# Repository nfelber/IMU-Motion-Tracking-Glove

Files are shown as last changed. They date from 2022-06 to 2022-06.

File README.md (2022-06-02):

# IMU Motion Tracking Glove

We propose a simple open source motion tracking glove prototype based on inertial measurement units (IMUs).
This project was meant to be achieved within a limited amount of time and there are therefore no plans to improve it further.
There are however a lot of potential improvement that can be made starting from our prototype, and anybody is welcome to use it for inspiration or as a base to build upon.

**Authors**: Sara Anejjar, Nathan Felber, Jad Tala, Nicolas S.

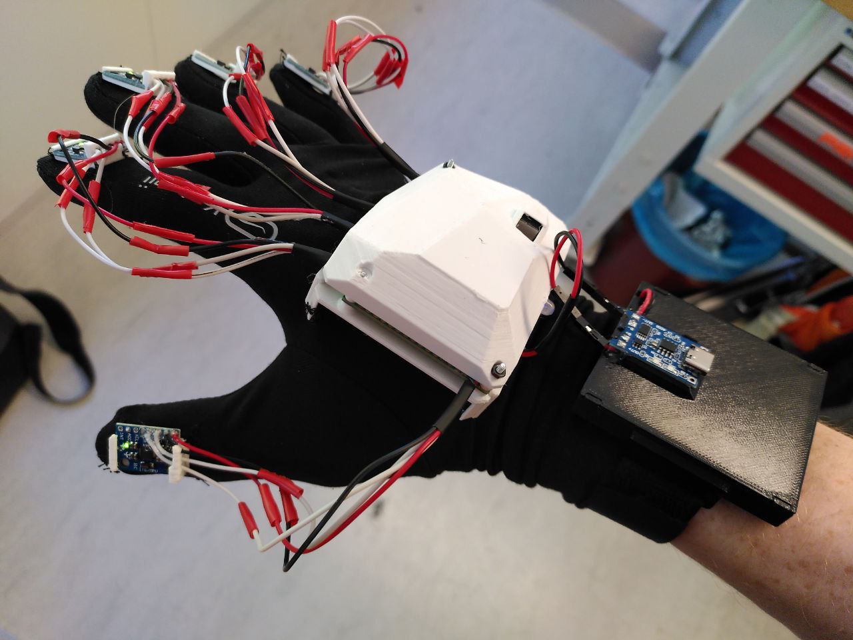
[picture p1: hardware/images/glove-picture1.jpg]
Our glove prototype


# Scope of the project

Many different technologies exist to perform hand and finger tracking, each with their advantages and drawbacks that we will not attempt to detail here.
We decided to explore the usage of IMUs for our prototype, as it is a technology which didn't seem to have been extensively used in motion tracking glove.
Our goal was to build a motion tracking glove from scratch without depending on proprietary VR hardware, and without depending on external computing (such as computer vision done on the user's computer).
Unfortunately, we were not able to do absolute positioning of the hand, which would have enabled our glove to be used in VR applications, but it should still be feasible with some more effort (see #Potential improvements).
Still, we were successfully able to build a prototype which collects and processes data from 6 IMUs, determines the likeliest pose and orientation of the hand from this data and sends the resulting skeleton of the hand to the computer via bluetooth.
We also wrote a driver for the device in Rust together with 3 demo applications.

# Challenges

Inertial measurement units have the advantage of providing a lot of data compared to simpler sensors (such as flex sensors) which allows for detection of a wider range of more subtle gestures.
In theory, that is.
The real challenge is that it is not straightforward to make sense of the data, and arbitrarily complex solutions can be implemented to produce better results.
For our prototype, we limited ourselves to computing the absolute orientation of each IMU, using our single 9-DoF IMU to compensate for the drift of the 5 others.
Our hand pose estimation model then only uses the orientation of the tip of each finger relative to the orientation of the back of the hand.
See #Potential improvements.

# How to replicate

Please refer to the `hardware` folder for how to build the glove itself.
All the software can be found in the `src` folder.

# Potential improvements

- Our prototype is equipped with a camera that could be used to do absolute positioning by detecting the position and distance of two colored markers, and combining this information with the orientation of the camera. Integration of the acceleration of the hand can be fused together with this data using a complementary filter to improve responsiveness and precision. Beware that the amount of image processing that can be done on the hardware we're using is very limited.
- Our pose estimation models only accounts for the orientation of the tip of each fingers. It could be improved by also using the measured dynamic acceleration to discriminate between two finger poses with similar fingertip orientations.

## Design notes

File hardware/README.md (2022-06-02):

# Building instructions

Here are the steps to follow in order to replicate our motion tracking glove prototype.

# Components

Here are listed the components we used.

- 1x ESP32-CAM
- 1x ESP8266 NodeMCU
- 5x MPU-6050 Breakout Board Module
- 1x Adafruit Precision NXP 9-DOF - FXOS8700 + FXAS21002
- 1x Battery Packs Li-Polymer Battery 3.7V 3000mAh
- 1x TC4056A Lithium Battery Charger and Protection Module
- 1x 24x18 holes universal soldering board
- 1x RGB Led (optional)
- 1x glove (running glove for example)

# 3D printed parts

We provide a file `motion-tracking-glove.3mf` ready to be printed with all the parts of the glove.
Please note that it might be better not to print them all at once, as they take a lot of space on the printer's plate.

All the CAD models are found in the `cad` folder.

# Circuit

we built our circuit on a universal soldering board, which made a good compromise between prototyping speed and robustness.

Here are the circuit schematics for the two sides of the soldering board.

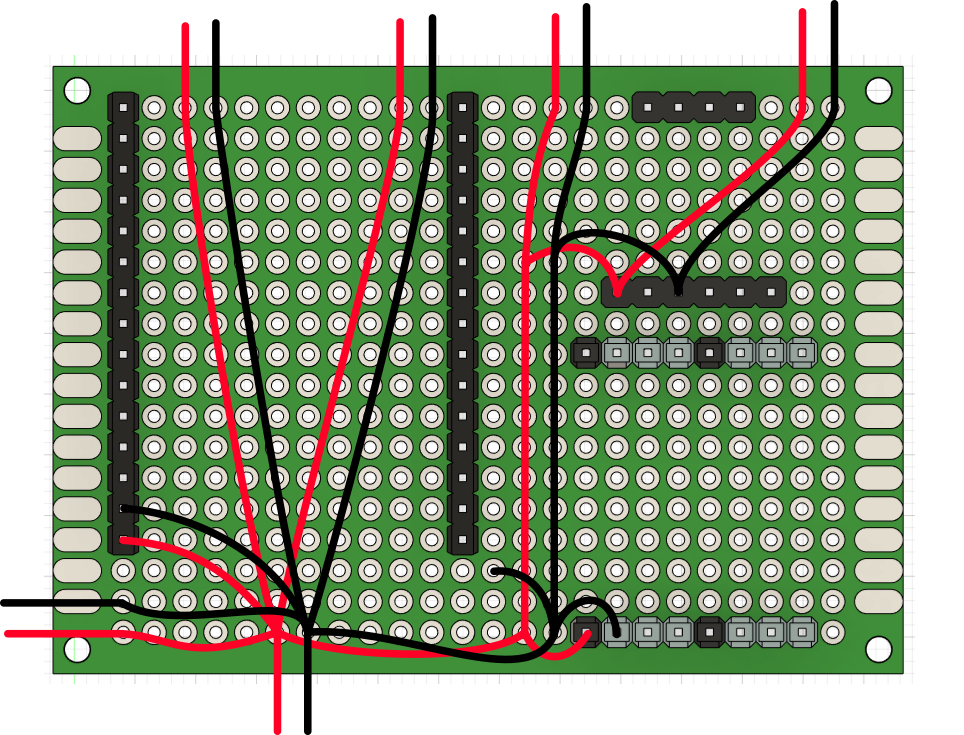
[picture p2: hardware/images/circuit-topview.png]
Top view


On the top side of the board, just under the ESPs and the NXP sensor are found the Vin and Gnd lines for the whole design.
The two wires coming from the bottom of the image are connected to the battery.
All the other wires going out of the image are connected to the corresponding pins of the MPU-6050s.

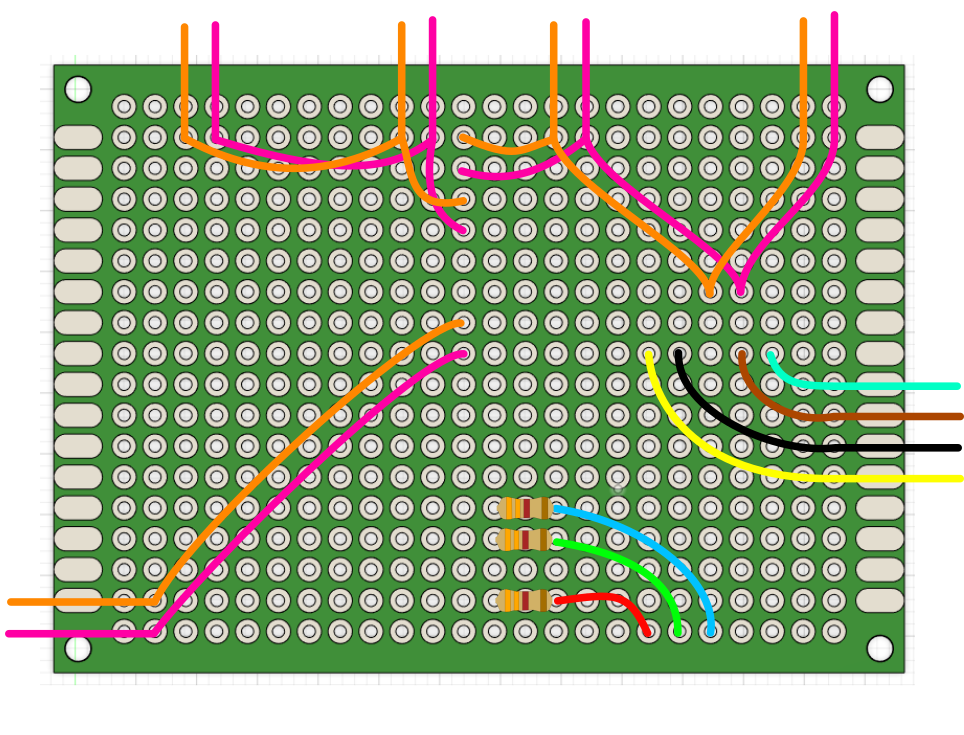
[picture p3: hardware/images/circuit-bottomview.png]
Bottom view


On the bottom side are the I2C lines (SCL: orange, SDA: pink), the RGB led connections (color-coded accordingly) and the 4 wires needed to program the ESP32-cam which doesn't have a USB port.
All the I2C wires going out of the image are connected to the corresponding pins of the MPU-6050s.

# Assembly

## Main part

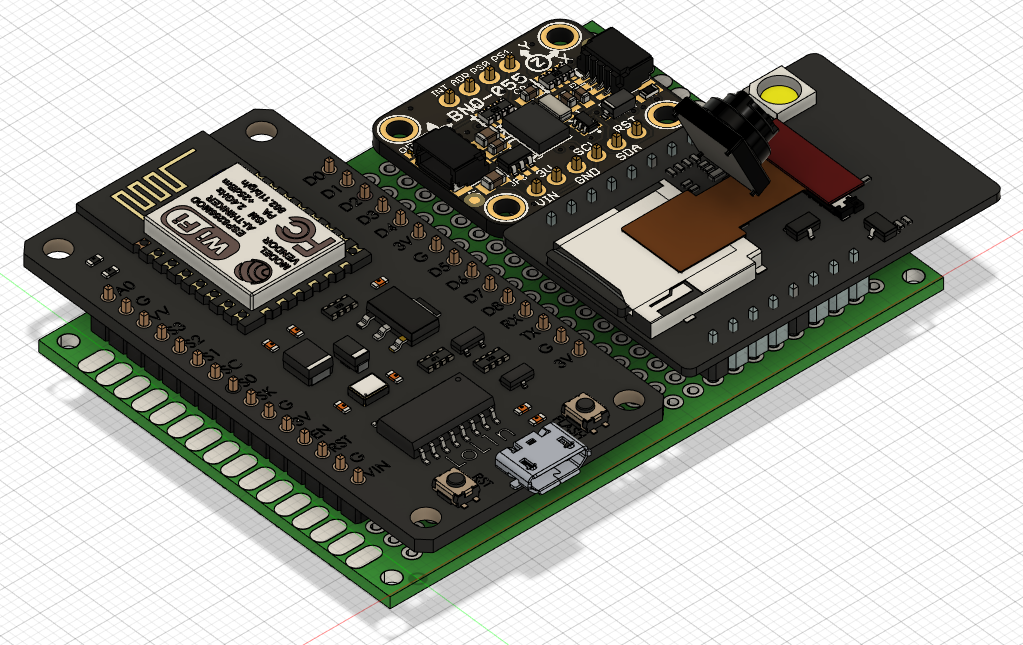
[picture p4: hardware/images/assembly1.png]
Step 1


After the wires have been fullly soldered to the circuit, place the ESP8266, the ESP-CAM, and the NXP sensor as shown in the above image.
Before soldering, verify that the circuit is working as it will be painful to desolder it afterwards.
Then solder the components to the board.
The RGB LED placement is not shown on the image, but each pin of the LED should be soldered at the corresponding place in the circuit.

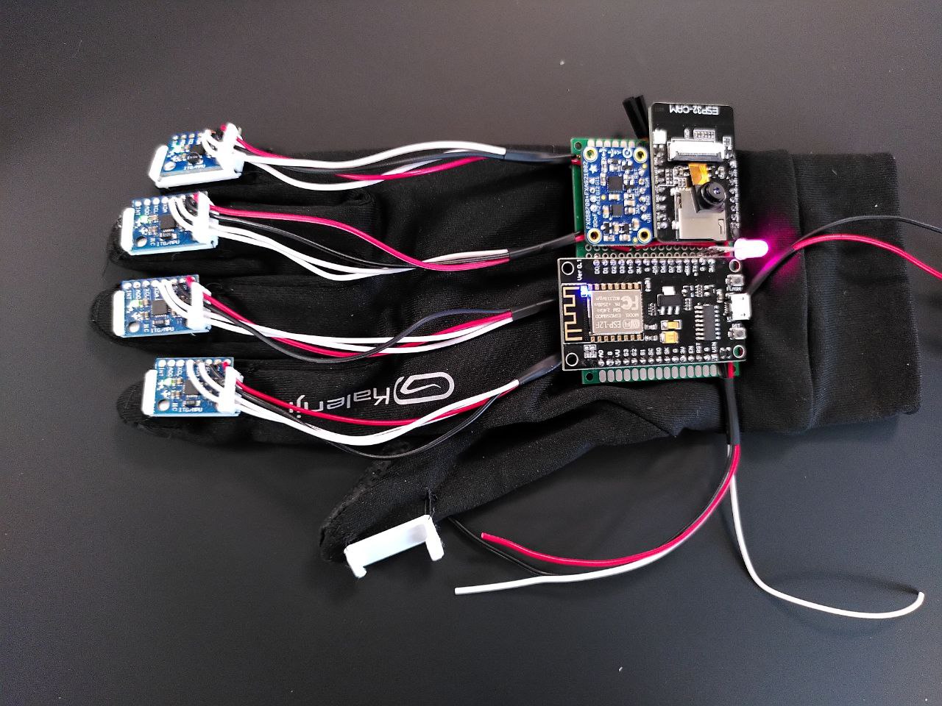
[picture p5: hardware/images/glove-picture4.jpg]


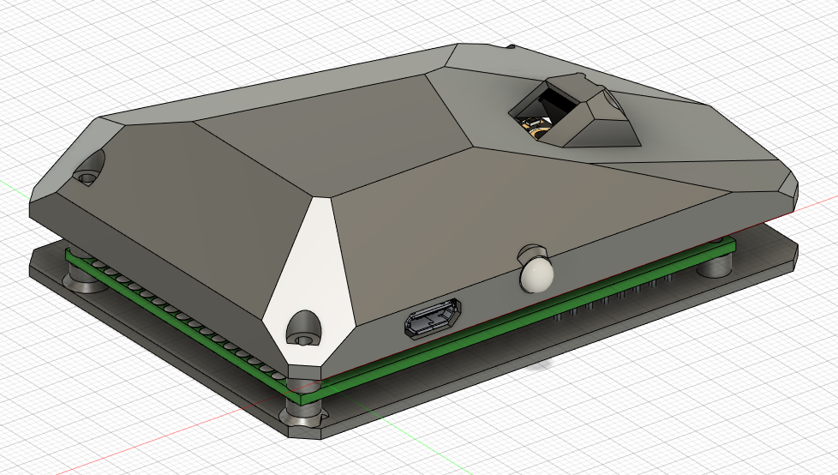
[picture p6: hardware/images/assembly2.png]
Step 2


Once the soldering is finished, assemble the cover and the base plate as shown in the image, and screw them together using M2 screws of the appropriate length.
The camera should be easy enough to fit in its enclosure using the little opening on the top of the cover.

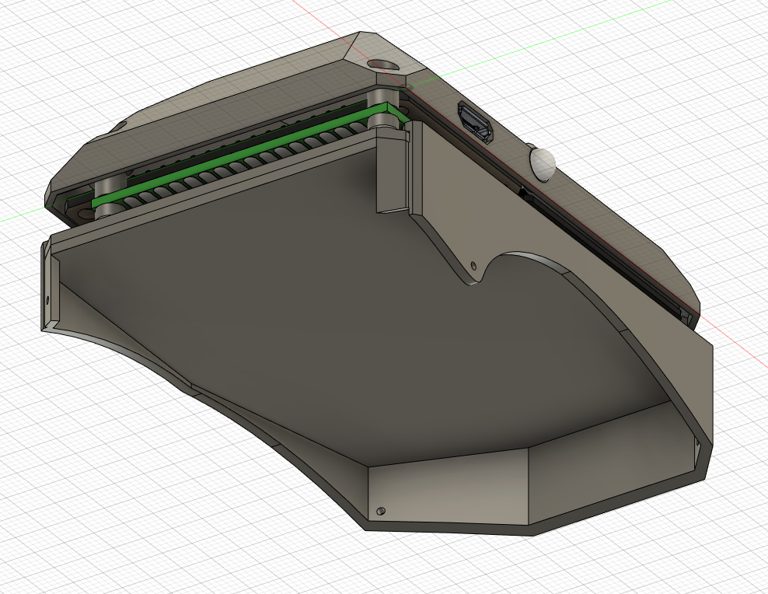
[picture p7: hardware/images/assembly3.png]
Step 3


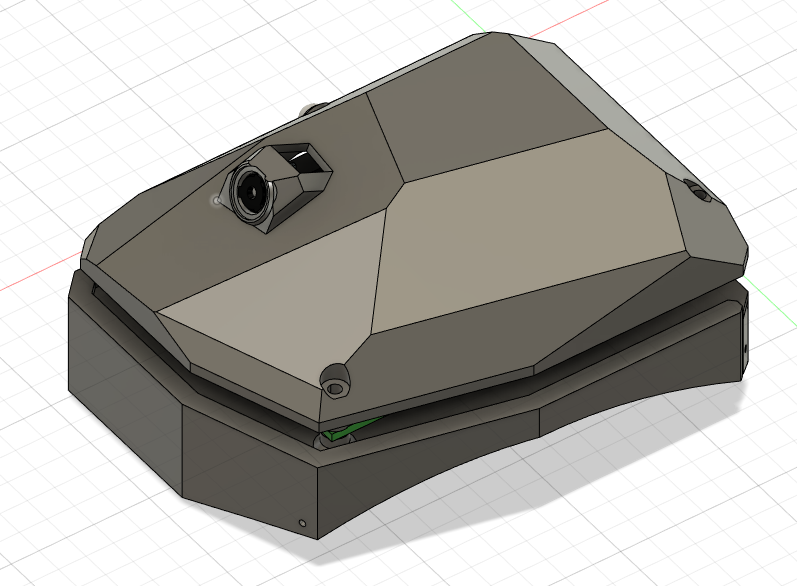
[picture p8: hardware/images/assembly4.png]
Step 4


The whole part can then be slid into main mount's rail.
This mount has 4 holes on its sides so that it can be sewed to the glove.

## MPU mount

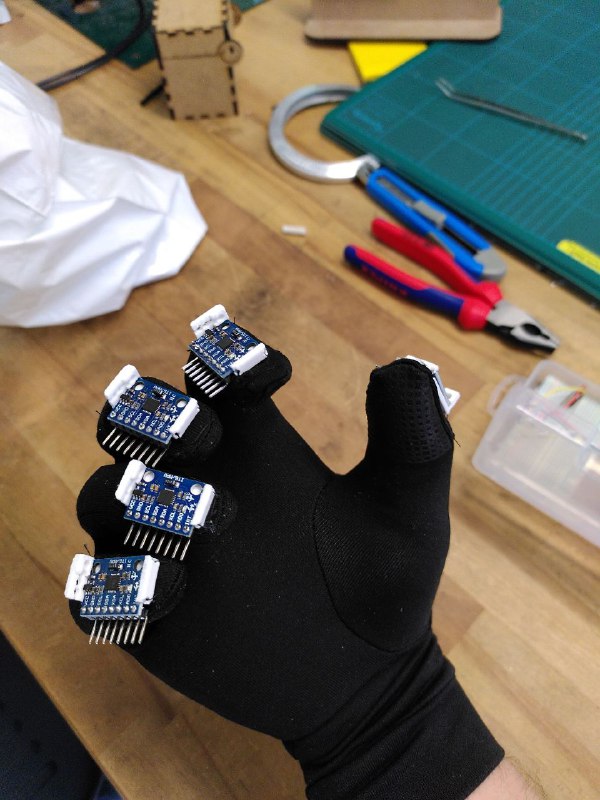
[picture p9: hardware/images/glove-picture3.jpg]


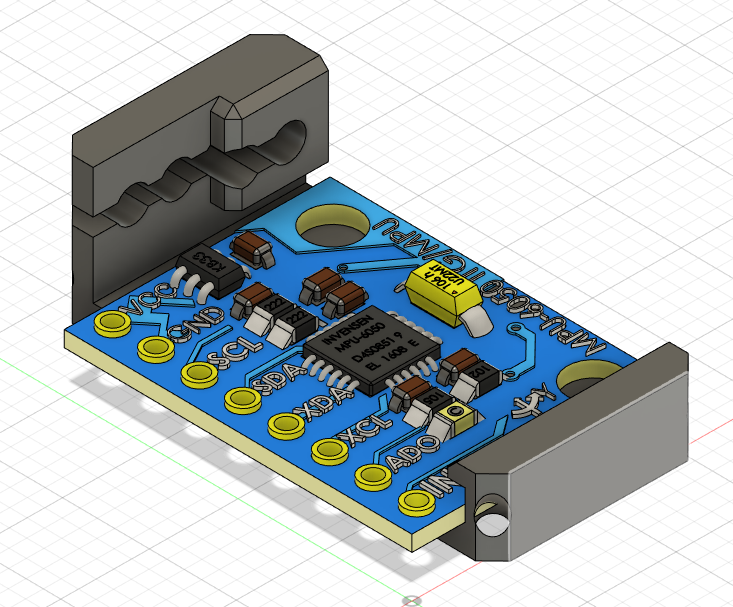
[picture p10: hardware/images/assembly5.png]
Step 5


The MPU-mount is pretty straightforward.
The MPU-6050 is meant to be slid into the rail, and the mount to be sewed to the fingertips of the glove using the four holes on the corners.

## Battery case

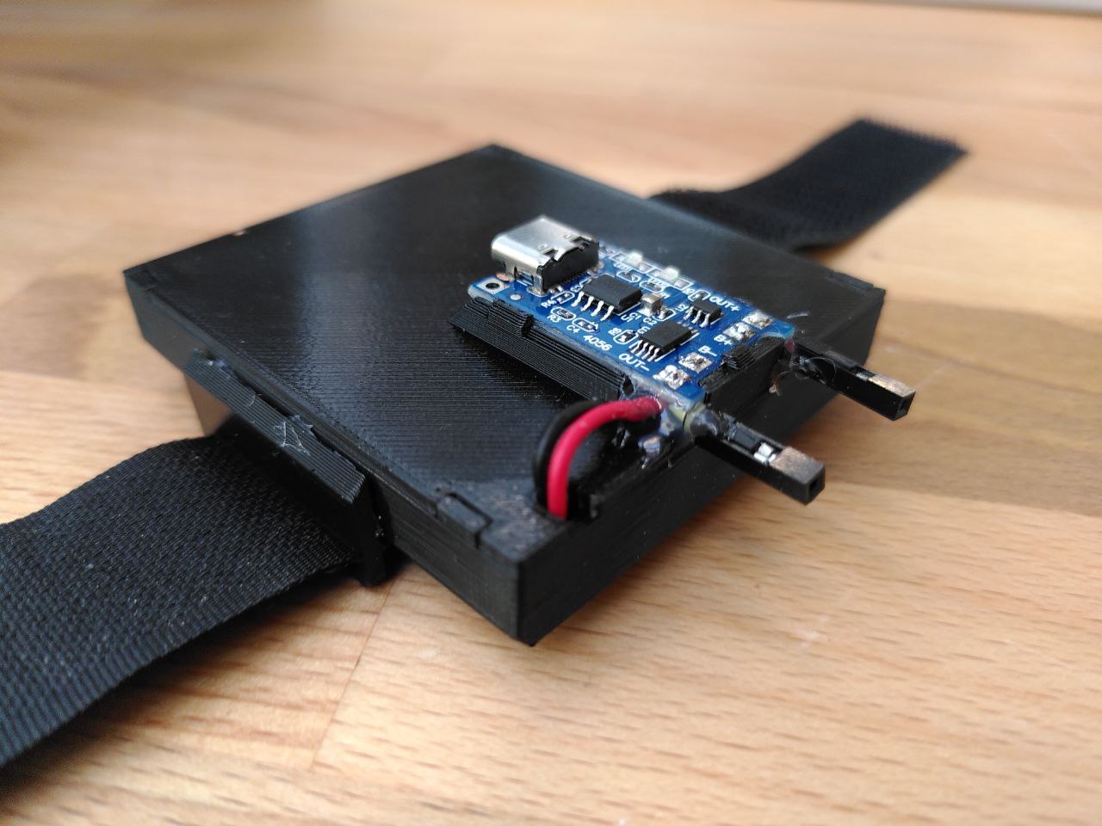
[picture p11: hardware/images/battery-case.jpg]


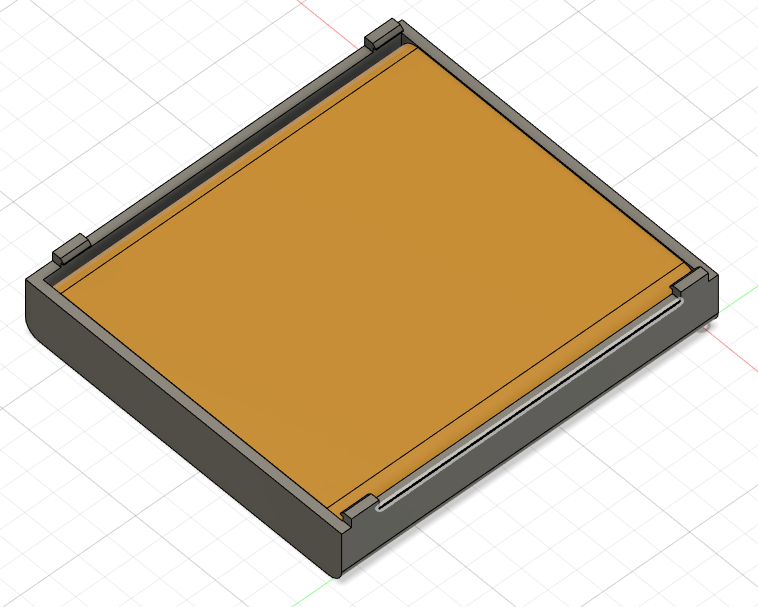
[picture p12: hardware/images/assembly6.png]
Step 6


Place the battery in the case.

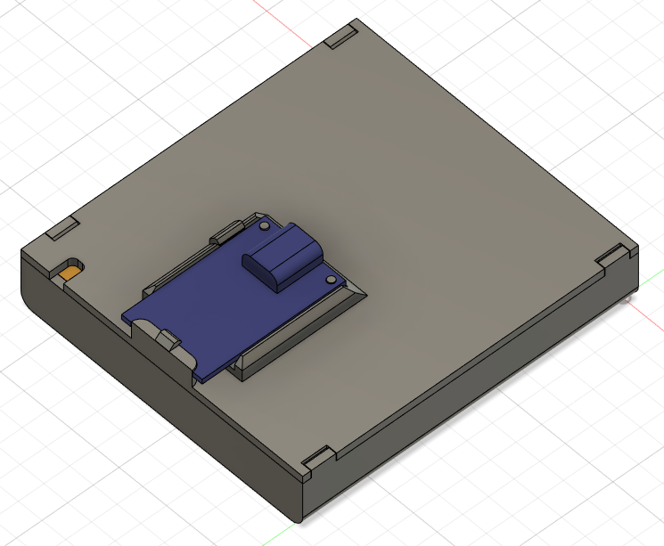
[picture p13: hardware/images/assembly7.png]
Step 7


Close the case with the cover which should snap in the right place.
Then fix the battery charger module as shown in the picture, after having soldered it to the battery wires.

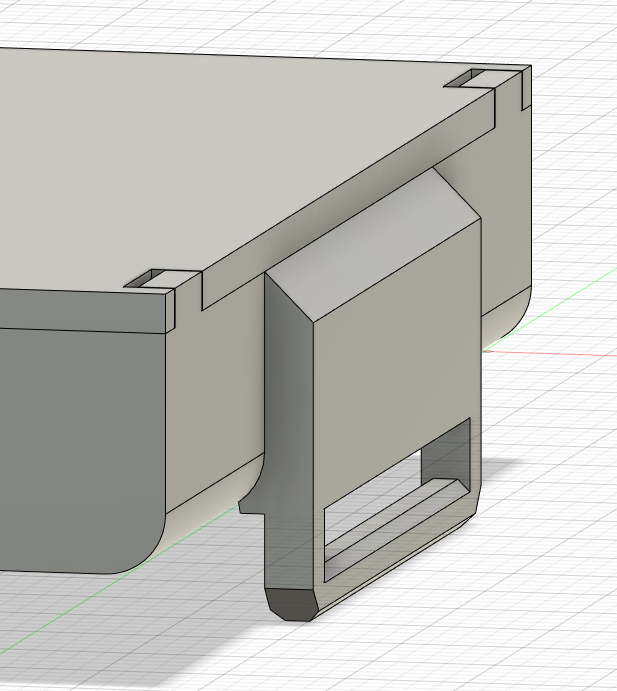
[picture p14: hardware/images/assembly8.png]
Step 8


Finally, fix the wristband loops to the side of the case using hot glue.

## Putting everything together

Here is how it looks when (almost) all the pieces have been put together:

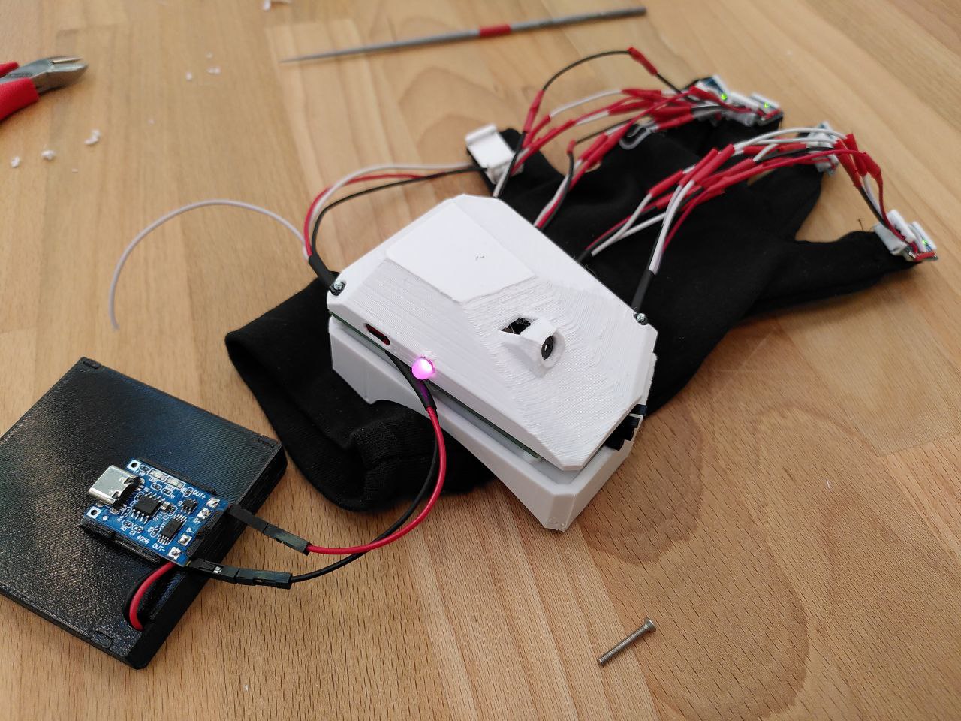
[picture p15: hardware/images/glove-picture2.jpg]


And the final prototype:

MPU mounts

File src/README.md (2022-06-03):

# Software conception

This document explains our software design.

## Dataflow

```
 _______  _______       _______                              _______________
|       ||       |     |       |                            |               |
|       ||       |     |       |                            |    Computer   |
|  MPU  ||  MPU  | ... |  NXP  |                            |               |
|       ||       |     |       |                            |_______________|
|_______||_______|     |_______|                            |...............|
    |        |      :      |                                |:::::::::::::::|
    |--------'------'------'                                |_____|___|_____|
    | I2C raw data                                                  |
 ___|_________                                                      |
|             |                                                     |
|             |                         _____________________       | BLE
|             |                        |                     |      |
|             |                        |                     |      |
|             |     ESP-NOW (wifi)     |                     |      |
|   ESP8266   | ---------------------> |      ESP32-CAM      | -----'
|             |      orientations      |                     |  hand skeleton
|             |                        |   pose-estimation   |
|     AHRS    |                        |_____________________|
|  algorithm  |
|_____________|

```

# ESP8266

The Arduino sketch for the esp8266 can be found inside the `esp8266` folder.
The program uses the [I2cdev](https://github.com/jrowberg/i2cdevlib) library to program the MPU-6050 and communicate with them using the I2C protocol.
It controls the NXP 9-DOF sensor similarily using the [Adafruit AHRS](https://github.com/adafruit/Adafruit_AHRS) library.

The program starts by initialising each sensor.
Then it programs the onboard digital motion processor found on each MPU-6050 so that all the sensor fusion is done on the sensor itself.
Finally, it reads and computes the orientation of each sensor as fast as possible in a 40 ms loop (25 Hz).
The orientation of the NXP sensor is given relative to the absolute (if I'm allowed this misuse of language) reference frame given by the gravity vector and the vector heading north.
The orientation of the MPUs are calculated relative to the orientation of the NXP, and their yaw angle is regularly updated using the NXP as a reference as they tend to drift with time otherwise.

At the end of each loop, these six orientations are then sent to the ESP32-CAM in the form of euler angles using the ESP-NOW wifi protocol.

# ESP32-CAM

The Arduino sketch for the esp8266 can be found inside the `esp32-ble` folder.
This program runs the pose estimation model whose goal is to reconstitute a skeleton of the hand using the orientation data.
The skeleton is composed of 20 joints: 4 for each finger except the thumb which only has 3 and one joint for the wrist.

All the joints have a position in cartesian space relative to the wrist which has position `(0, 0, 0)`.
This way, all the points can easily be translated if some information about the positioning of the hand would be found.

After each update, the program sends the data via bluetooth to the computer on which a running driver can retreive them.

# Rust driver

A simple driver written in [Rust](https://www.rust-lang.org/) can be found in the `MTG-driver` folder.
The crate is very straightforward to use and can provide all the glove's data as well as some very basic gestures detection.

# Demo software

## Debugger

The debugger, found in the `MTG-driver` folder is a simple plotter which displays the hand skeleton as well as all the received data on the screen.
To run it:

```console
$ cargo run --example debugger
```

## Music sequencer

A virtual music sequencer demo is provided in the `midi-sequencer` folder.
For it to work, the virtual loopback MIDI software [LoopMidi](https://www.tobias-erichsen.de/software/loopmidi.html) must be installed and running.
Then, run the program with:

```console
$ cargo run
```

and select the LoopMIDI port.
Then, the virtual MIDI port can be used with any [DAW](https://en.wikipedia.org/wiki/Digital_audio_workstation).

Four virtual knobs control the four notes of the sequencer loop.
Each of them can be grabbed by pinching in front of you with the thumb and a different finger.
There are four additionnal knobs that can be grabbed the same way, but pinching towards the floor.
These additional knobs control the frequency, the cutoff, the base height of every note and the scale that is used.

## Flappy bird

The detailed description of the Flappy Bird game can be found under the following link:
https://github.com/nfelber/IMU-Motion-Tracking-Glove/tree/main/src/flappy_bird

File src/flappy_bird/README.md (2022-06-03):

# FlappyBird
This directory is contains the code and image files allowing to play the Flappy Bird game.

## Launching the Flappy Bird game
To launch the game, follow these steps:

1. Install necessary pygame module by using the command ```pip install pygame```
2. Launch the game using the command ```python3 bird.py```

## Description of our implementation of the Flappy Bird game
Our game is based on the original Flappy Bird game developped by Dong Nguyen in 2013. The gameplay has several particularities that distinguish it from the initial gameplay:
1. There is a chance of 1/3 that instead of a pipe, the player will encounter a wall. The wall cannot be avoided and must thus be "destroyed" by the player making relevant interraction. 
2. In a random manner, the bird enters once every while into a state of madness because of flying without any break. During the state of madness, player loses his control over the bird. The bird will be no longer be willing to react to the player's command to flap his wings. To regain control over the bird, the player has to make relevant interraction.
3. Bird can float in the space at the same level by the player making relevant interraction. While the bird is floating, it will no longer be falling on the ground. However, when the bird enters into the madness state, it is too tired and cannot float anymore.

The goal of the game is to gain the highest score possible. The score is incremented every time that the bird flies between two pipes. The game is over when the bird falls on the ground by either hitting a pipe, a wall or the sky.

## Gameplay
Player can interract with the game's environment in the following manners:
1. By moving the glove fast enough or clicking on the mouse, the flappy bird will flap his wings and jump higher in space.
2. By making gesture 1 or pressing space, any wall that the player encounters gets destroyed.
2. By making gesture 2 or pressing n during the state of madness, the bird becomes normal once again and the player regains control over it.
3. By making gesture 3 or holding h, the bird floats at the same level in space.
4. By making gesture 4 or pressing the button on the screen, player can reset the game.

## Gestures
The gestures that the player can make are the following:
1. Gesture 1: bend all your fingers
2. Gesture 2: bend your index and little finger
3. Gesture 3: bend your middle finger, ring finger and little finger
4. Gesture 4: bend your thumb, ring and little finger

## Source of used images:
The images that our game uses come from the following sources:
- Flappy Bird texture 1: https://openclipart.org/detail/239673/flying-bird-3-frame-1
- Flappy Bird texture 2: https://openclipart.org/detail/239674/flying-bird-3-frame-2
- Flappy Bird texture 3: https://openclipart.org/detail/239675/flying-bird-3-frame-3
- Flappy Bird texture 4: https://openclipart.org/detail/239676/flying-bird-3-frame-4
- Background: http://clipart-library.com/clipart/761360.htm
- Ground: https://www.pikpng.com/pngvi/hmimmh_ground-flappy-bird-ground-scratch-clipart/
- Pipe: https://www.nicepng.com/ourpic/u2q8w7e6e6y3o0q8_flappy-bird-pipes-png-bottle/
- Brick wall obstacle: https://www.pngwing.com/en/free-png-zbvly
- Game over skull texture: https://openclipart.org/detail/248773/skull-and-cross-bones

All images that are not listed here come are images that were created by us by modifying aforementionned images.

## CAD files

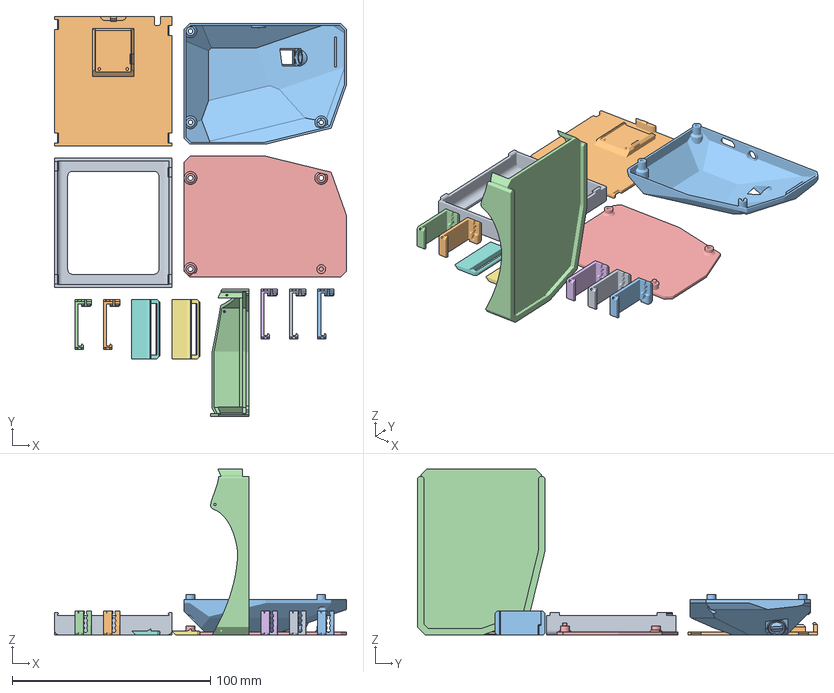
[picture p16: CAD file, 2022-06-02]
hardware/motion-tracking-glove.3mf
147.4 x 201.9 x 83.7 mm
battery-case-bottom.stl
battery-case-top.stl
cover.stl
fixation.stl
main-mount.stl
mpu-mount.stl x 5
wristband.stl x 2

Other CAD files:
hardware/cad/battery-case.f3d
hardware/cad/mpu-mount .f3z

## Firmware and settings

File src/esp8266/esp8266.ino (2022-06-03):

#include "I2Cdev.h"
#include "MPU6050_6Axis_MotionApps612.h"
#include "Wire.h"
#include <Adafruit_Sensor_Calibration.h>
#include <Adafruit_AHRS.h>
#include <Adafruit_FXAS21002C.h>
#include <Adafruit_FXOS8700.h>

#include <Arduino.h>
#include <ESP8266WiFi.h>
#include <espnow.h>

Adafruit_Sensor *accelerometer, *gyroscope, *magnetometer;
Adafruit_NXPSensorFusion filter;
#if defined(ADAFRUIT_SENSOR_CALIBRATION_USE_EEPROM)
  Adafruit_Sensor_Calibration_EEPROM cal;
#else
  Adafruit_Sensor_Calibration_SDFat cal;
#endif

#define FILTER_UPDATE_RATE_HZ 25
//#define FILTER_UPDATE_RATE_HZ 34
Adafruit_FXOS8700 fxos = Adafruit_FXOS8700(0x8700A, 0x8700B);
Adafruit_FXAS21002C fxas = Adafruit_FXAS21002C(0x0021002C);


const int offsets[30] = {
  -2250,  733,  360,  37, 21, -167,
  -3392,  347,  176,  -39,  39, -45,
  -1518,  2031, 1416, 62, -6, 52,
  -312, -3249,  1576, -354, 33, 66,
  -348, 523,  848,  67, 128,  9
};

const int I2C_BUS0_SDA = 12;
const int I2C_BUS0_SCL = 14;
const int I2C_BUS12_SDA = 2;
const int I2C_BUS12_SCL = 0;
const int I2C_BUS34_SDA = 4;
const int I2C_BUS34_SCL = 5;

const int I2C_FREQ = 400000;
const int DMP_PACKET_SIZE = 28;

MPU6050 sensor0(0x68);
MPU6050 sensor1(0x68);
MPU6050 sensor2(0x69);
MPU6050 sensor3(0x68);
MPU6050 sensor4(0x69);

bool dmpReady = false;  // set true if DMP init was successful
uint16_t packetSize;    // expected DMP packet size (default is 42 bytes)
uint16_t fifoCount;     // count of all bytes currently in FIFO
uint8_t fifoBuffer[64]; // FIFO storage buffer

uint8_t broadcastAddress[] = {0xB4, 0xE6, 0x2D, 0xF9, 0x90, 0x45};

typedef struct {
  float euler0[3];
  float euler1[3];
  float euler2[3];
  float euler3[3];
  float euler4[3];
  float euler5[3];
} data_t;

data_t angles;
Quaternion nxp_q, zRotation0, zRotation1, zRotation2, zRotation3, zRotation4;

void setup() {
  Serial.begin(115200);
  Serial.println("Setting up wifi...");
  
  WiFi.mode(WIFI_STA);
  
  // Get Mac Add
  Serial.print("Mac Address: ");
  Serial.println(WiFi.macAddress());
  Serial.println("ESP-Now Sender");
  
  // Initializing the ESP-NOW
  if (esp_now_init() != 0) {
    Serial.println("Problem during ESP-NOW init");
    return;
  }
  
  esp_now_set_self_role(ESP_NOW_ROLE_CONTROLLER);
  
  esp_now_add_peer(broadcastAddress, ESP_NOW_ROLE_SLAVE, 1, NULL, 0);
  Serial.println("Added peer ESP32.");
  
  esp_now_register_send_cb(onSent);
  
  Serial.println("Successfully initialized wifi.");
  
  Serial.println(F("\nInitializing I2C devices..."));
  Serial.println(F("Sensor0:"));
  init_sensor(sensor0, &offsets[0], I2C_BUS0_SDA, I2C_BUS0_SCL);
  Serial.println(F("Sensor1:"));
  init_sensor(sensor1, &offsets[6], I2C_BUS12_SDA, I2C_BUS12_SCL);
  Serial.println(F("Sensor2:"));
  init_sensor(sensor2, &offsets[12], I2C_BUS12_SDA, I2C_BUS12_SCL);
  Serial.println(F("Sensor3:"));
  init_sensor(sensor3, &offsets[18], I2C_BUS34_SDA, I2C_BUS34_SCL);
  Serial.println(F("Sensor4:"));
  init_sensor(sensor4, &offsets[24], I2C_BUS34_SDA, I2C_BUS34_SCL);
  Serial.println(F("Sensor5:"));
  init_NXP(I2C_BUS34_SDA, I2C_BUS34_SCL);

  Serial.println(F("\nInitializing I2C devices..."));
  Serial.println(F("Sensor0:"));
  program_sensor(sensor0, I2C_BUS0_SDA, I2C_BUS0_SCL);
  Serial.println(F("Sensor1:"));
  program_sensor(sensor1, I2C_BUS12_SDA, I2C_BUS12_SCL);
  Serial.println(F("Sensor2:"));
  program_sensor(sensor2, I2C_BUS12_SDA, I2C_BUS12_SCL);
  Serial.println(F("Sensor3:"));
  program_sensor(sensor3, I2C_BUS34_SDA, I2C_BUS34_SCL);
  Serial.println(F("Sensor4:"));
  program_sensor(sensor4, I2C_BUS34_SDA, I2C_BUS34_SCL);
  
  filter.begin(FILTER_UPDATE_RATE_HZ);
  unsigned long t;
  while (true) {
    t = millis();
    read_sensors();
    print_euler(angles.euler0);
    Serial.print(" | ");
    print_euler(angles.euler1);
    Serial.print(" | ");
    print_euler(angles.euler2);
    Serial.print(" | ");
    print_euler(angles.euler3);
    Serial.print(" | ");
    print_euler(angles.euler4);
    Serial.print(" | ");
    print_euler(angles.euler5);
    
    Serial.print(" - ");
    Serial.println(millis() - t);

    send_data();
  }
}

void loop() {
//  Serial.println(F("\ni=init, p=program, c=calibrate, r=read: "));
//  while (!Serial.available());
//  char c = Serial.read();
//
//  if (c == 'i') {
//    Serial.println(F("\nInitializing I2C devices..."));
//    Serial.println(F("Sensor0:"));
//    init_sensor(sensor0, &offsets[0], I2C_BUS0_SDA, I2C_BUS0_SCL);
//    Serial.println(F("Sensor1:"));
//    init_sensor(sensor1, &offsets[6], I2C_BUS12_SDA, I2C_BUS12_SCL);
//    Serial.println(F("Sensor2:"));
//    init_sensor(sensor2, &offsets[12], I2C_BUS12_SDA, I2C_BUS12_SCL);
//    Serial.println(F("Sensor3:"));
//    init_sensor(sensor3, &offsets[18], I2C_BUS34_SDA, I2C_BUS34_SCL);
//    Serial.println(F("Sensor4:"));
//    init_sensor(sensor4, &offsets[24], I2C_BUS34_SDA, I2C_BUS34_SCL);
//    Serial.println(F("Sensor5:"));
//    init_NXP(I2C_BUS34_SDA, I2C_BUS34_SCL);
//  } else if (c == 'p') {
//    Serial.println(F("\nInitializing I2C devices..."));
//    Serial.println(F("Sensor0:"));
//    program_sensor(sensor0, I2C_BUS0_SDA, I2C_BUS0_SCL);
//    Serial.println(F("Sensor1:"));
//    program_sensor(sensor1, I2C_BUS12_SDA, I2C_BUS12_SCL);
//    Serial.println(F("Sensor2:"));
//    program_sensor(sensor2, I2C_BUS12_SDA, I2C_BUS12_SCL);
//    Serial.println(F("Sensor3:"));
//    program_sensor(sensor3, I2C_BUS34_SDA, I2C_BUS34_SCL);
//    Serial.println(F("Sensor4:"));
//    program_sensor(sensor4, I2C_BUS34_SDA, I2C_BUS34_SCL);
//  } else if (c == 'c') {
//    Serial.println(F("\nInitializing I2C devices..."));
//    Serial.println(F("Sensor0:"));
//    calibrate_sensor(sensor0, I2C_BUS0_SDA, I2C_BUS0_SCL);
//    Serial.println(F("Sensor1:"));
//    calibrate_sensor(sensor1, I2C_BUS12_SDA, I2C_BUS12_SCL);
//    Serial.println(F("Sensor2:"));
//    calibrate_sensor(sensor2, I2C_BUS12_SDA, I2C_BUS12_SCL);
//    Serial.println(F("Sensor3:"));
//    calibrate_sensor(sensor3, I2C_BUS34_SDA, I2C_BUS34_SCL);
//    Serial.println(F("Sensor4:"));
//    calibrate_sensor(sensor4, I2C_BUS34_SDA, I2C_BUS34_SCL);
//  } else if (c == 'r') {
//    filter.begin(FILTER_UPDATE_RATE_HZ);
//    unsigned long t;
//    while (true) {
//      t = millis();
//      read_sensors();
//      print_euler(angles.euler0);
//      Serial.print(" | ");
//      print_euler(angles.euler1);
//      Serial.print(" | ");
//      print_euler(angles.euler2);
//      Serial.print(" | ");
//      print_euler(angles.euler3);
//      Serial.print(" | ");
//      print_euler(angles.euler4);
//      Serial.print(" | ");
//      print_euler(angles.euler5);
//      
////      Serial.println();
//      Serial.print(" - ");
//      Serial.println(millis() - t);
//
//      send_data();
//    }
//  }
}

void print_euler(float* euler) {
  Serial.print(euler[0] * 180/M_PI);
  Serial.print(" ");
  Serial.print(euler[1] * 180/M_PI);
  Serial.print(" ");
  Serial.print(euler[2] * 180/M_PI);
}

void mpu_read_sensor(MPU6050 &sensor, float *euler, Quaternion &zRotation) {
  Quaternion q;
  float euler_tmp[3];
  getFIFOReadingAtReset(sensor, fifoBuffer);
  
  sensor.dmpGetQuaternion(&q, fifoBuffer);
//  Quaternion qf = nxp_q.getConjugate().getProduct(q);
//  sensor.dmpGetEuler(euler_tmp, &qf);

  if (abs(angles.euler5[0]) < 0.1 && abs(angles.euler5[1]) < 0.1) {
    float theta_z0 = atan2(q.z, q.w);
    zRotation = {cos(theta_z0), 0, 0, sin(theta_z0)};
  }
  float theta_z1= atan2(nxp_q.z, nxp_q.w);
  Quaternion zRotation5 = {cos(theta_z1), 0, 0, sin(theta_z1)};
  Quaternion qt = zRotation.getConjugate().getProduct(q);
  qt = zRotation5.getProduct(qt);
  Quaternion qf = nxp_q.getConjugate().getProduct(qt);
  
  sensor.dmpGetEuler(euler_tmp, &qf);
  
  euler[0] = -euler_tmp[1];
  euler[1] = euler_tmp[2];
  euler[2] = euler_tmp[0];
}

void nxp_read_sensor(float *euler) {
  sensors_event_t accel, gyro, mag;
  accelerometer->getEvent(&accel);
  gyroscope->getEvent(&gyro);
  magnetometer->getEvent(&mag);
  cal.calibrate(mag);
  cal.calibrate(accel);
  cal.calibrate(gyro);
  float gx, gy, gz;
  gx = gyro.gyro.x * SENSORS_RADS_TO_DPS;
  gy = gyro.gyro.y * SENSORS_RADS_TO_DPS;
  gz = gyro.gyro.z * SENSORS_RADS_TO_DPS;
  filter.update(gx, gy, gz, 
                accel.acceleration.x, accel.acceleration.y, accel.acceleration.z, 
                mag.magnetic.x, mag.magnetic.y, mag.magnetic.z);

  filter.getQuaternion(&nxp_q.w, &nxp_q.x, &nxp_q.y, &nxp_q.z);
  float euler_tmp[3];
  sensor0.dmpGetEuler(euler_tmp, &nxp_q);
  euler[0] = -euler_tmp[1];
  euler[1] = euler_tmp[2];
  euler[2] = euler_tmp[0];
}

void read_sensors() {
  Wire.begin(I2C_BUS0_SDA, I2C_BUS0_SCL, I2C_FREQ);
  sensor0.resetFIFO();
  Wire.begin(I2C_BUS12_SDA, I2C_BUS12_SCL, I2C_FREQ);
  sensor1.resetFIFO();
  sensor2.resetFIFO();
  Wire.begin(I2C_BUS34_SDA, I2C_BUS34_SCL, I2C_FREQ);
  sensor3.resetFIFO();
  sensor4.resetFIFO();

  nxp_read_sensor(angles.euler5);
  
  Wire.begin(I2C_BUS0_SDA, I2C_BUS0_SCL, I2C_FREQ);
  
  mpu_read_sensor(sensor0, angles.euler0, zRotation0);
  
  Wire.begin(I2C_BUS12_SDA, I2C_BUS12_SCL, I2C_FREQ);
  
  mpu_read_sensor(sensor1, angles.euler1, zRotation1);
  
  mpu_read_sensor(sensor2, angles.euler2, zRotation2);
  
  Wire.begin(I2C_BUS34_SDA, I2C_BUS34_SCL, I2C_FREQ);
  
  mpu_read_sensor(sensor3, angles.euler3, zRotation3);

  mpu_read_sensor(sensor4, angles.euler4, zRotation4);
}

void calibrate_sensor(MPU6050 &sensor, int sda, int scl) {
  Wire.begin(sda, scl, I2C_FREQ);

  sensor.CalibrateAccel(6);
  sensor.CalibrateGyro(6);
  sensor.PrintActiveOffsets();
}

void program_sensor(MPU6050 &sensor, int sda, int scl) {
  Wire.begin(sda, scl, I2C_FREQ);
  
  // load and configure the DMP
  Serial.println(F("Initializing DMP..."));
  int devStatus = sensor.dmpInitialize();


  // make sure it worked (returns 0 if so)
  if (devStatus == 0) {
      
      // turn on the DMP, now that it's ready
      Serial.println(F("Enabling DMP..."));
      sensor.setDMPEnabled(true);

      // get expected DMP packet size for later comparison
      packetSize = sensor.dmpGetFIFOPacketSize();
  } else {
      // ERROR!
      // 1 = initial memory load failed
      // 2 = DMP configuration updates failed
      // (if it's going to break, usually the code will be 1)
      Serial.print(F("DMP Initialization failed (code "));
      Serial.print(devStatus);
      Serial.println(F(")"));
  }
}

void send_data() {
  esp_now_send(NULL, (uint8_t *) &angles, sizeof(data_t));
}

void onSent(uint8_t *mac_addr, uint8_t sendStatus) {
//  Serial.print("Status: ");
//  Serial.println(sendStatus);
}

void init_sensor(MPU6050 &sensor, const int *offsets, int sda, int scl) {
  Wire.begin(sda, scl, I2C_FREQ);

  // initialize device
  sensor.initialize();
  sensor.setRate(7);

  // verify connection
  Serial.println(F("Testing device connection..."));
  Serial.println(sensor.testConnection() ? F("MPU6050 connection successful") : F("MPU6050 connection failed"));

  sensor1.setXAccelOffset(offsets[0]);
  sensor1.setYAccelOffset(offsets[1]);
  sensor1.setZAccelOffset(offsets[2]);
  sensor1.setXGyroOffset(offsets[3]);
  sensor1.setYGyroOffset(offsets[4]);
  sensor1.setZGyroOffset(offsets[5]);
  Serial.println(F("Calibration loaded."));
}

void init_NXP(int sda, int scl) {
  Wire.begin(sda, scl, I2C_FREQ);
  cal.begin();
  if (! cal.loadCalibration()) {
    Serial.println("No calibration loaded/found");
  } else {
    Serial.println("Calibration loaded.");
  }
  if (!fxos.begin() || !fxas.begin()) {
    Serial.println("NXP connection failed");
    return;
  }
  
  accelerometer = fxos.getAccelerometerSensor();
  gyroscope = &fxas;
  magnetometer = fxos.getMagnetometerSensor();

  Serial.println("NXP connection successful");
}

void getFIFOReadingAtReset(MPU6050 &sensor, uint8_t *data) {
  while (sensor.getFIFOCount() < DMP_PACKET_SIZE) {}
  sensor.getFIFOBytes(data, DMP_PACKET_SIZE);
}

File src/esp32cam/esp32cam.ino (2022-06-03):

#include <WiFi.h>
#include <esp_now.h>

#include <BLEDevice.h>
#include <BLEUtils.h>
#include <BLEServer.h>
#include <BLE2902.h>

const int RED_PIN = 13;
const int GREEN_PIN = 14;
const int BLUE_PIN = 15;

typedef struct {
  float roll;
  float pitch;
  float yaw;
} angle_t;

typedef struct {
  float x;
  float y;
  float z;
} Vector3;

typedef struct {
  angle_t euler0; //thumb
  angle_t euler1; //forefinger 
  angle_t euler2; //middle
  angle_t euler3; //ring
  angle_t euler4; //pinky
  angle_t euler5; //backHand
} data_t;

data_t angles;

typedef struct {
  float size;
  angle_t angle;
} Bone;

typedef struct {
  std::vector<Bone> bones;
} Finger;

Finger thumb;
Finger forefinger;
Finger middle;
Finger ring;
Finger little;

typedef struct {
  Vector3 palm_coords[1];
  Vector3 thumb_coords[3];
  Vector3 forefinger_coords[4];
  Vector3 middle_coords[4];
  Vector3 ring_coords[4];
  Vector3 little_coords[4];

  angle_t palm_euler;
  angle_t thumb_euler;
  angle_t forefinger_euler;
  angle_t middle_euler;
  angle_t ring_euler;
  angle_t little_euler;
} model_data_t;

// Bluetooth specific
BLEServer* pServer = NULL;
BLECharacteristic* pCharacteristic = NULL;
bool deviceConnected = false;
bool oldDeviceConnected = false;

#define SERVICE_UUID        "87f0e59e-08a7-4a00-9c0e-ed3732924c41"
#define CHARACTERISTIC_UUID "dc931335-7019-4096-b1e7-42a29e570f8f"

std::vector<Vector3> forward_kinematics(Finger &finger) {
  Vector3 lastPoint = { 0.0, 0.0, 0.0 };
  angle_t lastAngle = { 0.0, 0.0, 0.0 };
  std::vector<Vector3> v;
  for(const Bone& bone: finger.bones) {
    lastAngle = { lastAngle.roll + bone.angle.roll,
                  lastAngle.pitch + bone.angle.pitch,
                  lastAngle.yaw + bone.angle.yaw };
    Vector3 new_vec = rotate((Vector3) { bone.size, 0.0, 0.0 }, &lastAngle);
    lastPoint = { lastPoint.x + new_vec.x, lastPoint.y + new_vec.y, lastPoint.z + new_vec.z };
    v.push_back(lastPoint);
  }
  return v;
}

Vector3 rotate(Vector3 v, angle_t *angle) {
  float cr = cosf(angle->roll);
  float cp = cosf(angle->pitch);
  float cy = cosf(angle->yaw);
  float sr = sinf(angle->roll);
  float sp = sinf(angle->pitch);
  float sy = sinf(angle->yaw);

  float cysp = cy * sp;
  float sysp = sy * sp;

  return (Vector3) { 
    cy*cp * v.x + (cysp*sr - sy*cr) * v.y + (cysp*cr + sy*sr) * v.z,
    sy*cp * v.x + (sysp*sr + cy*cr) * v.y + (sysp*cr + cy*sr) * v.z,
    -sp * v.x + cp*sr * v.y + cp*cr * v.z };
}

void onDataRecv(const uint8_t * mac, const uint8_t *incomingData, int len)
{
  memcpy(&angles, incomingData, sizeof(data_t));

  model_data_t m_data = {0};

  thumb.bones = { (Bone) {0.0, angles.euler5 },
                  (Bone) {7.0, (angle_t) {-45.0 / 180.0 * PI, -30.0 / 180.0 * PI, -45.0 / 180.0 * PI} },
                  (Bone) {5.0, (angle_t) {0.0, angles.euler0.pitch / 2, 0.0} },
                  (Bone) {3.0, (angle_t) {0.0, angles.euler0.pitch / 2, 0.0} } };
                  
  forefinger.bones = { (Bone) {0.0, angles.euler5 },
                  (Bone) {10.0, (angle_t) {0.0, 0.0, -10.0 / 180.0 * PI} },
                  (Bone) {4.0, (angle_t) {0.0, angles.euler1.pitch / 3, 0.0} },
                  (Bone) {3.0, (angle_t) {0.0, angles.euler1.pitch / 3, 0.0}},
                  (Bone) {3.0, (angle_t) {0.0, angles.euler1.pitch / 3, 0.0}} 
                  };
                  
  middle.bones = { (Bone) {0.0, angles.euler5 },
                  (Bone) {10.0, (angle_t) {0.0, 0.0, 0.0} },
                  (Bone) {4.0, (angle_t) {0.0, angles.euler2.pitch / 3, 0.0}},
                  (Bone) {3.0, (angle_t) {0.0, angles.euler2.pitch / 3, 0.0}},
                  (Bone) {3.0, (angle_t) {0.0, angles.euler2.pitch / 3, 0.0}} };
                  
  ring.bones = { (Bone) {0.0, angles.euler5 },
                  (Bone) {10.0, (angle_t) {0.0, 0.0, 10.0 / 180.0 * PI} },
                  (Bone) {4.0, (angle_t) {0.0, angles.euler3.pitch / 3, 0.0}},
                  (Bone) {3.0, (angle_t) {0.0, angles.euler3.pitch / 3, 0.0}},
                  (Bone) {3.0, (angle_t) {0.0, angles.euler3.pitch / 3, 0.0}} };
                  
  little.bones = { (Bone) {0.0, angles.euler5 },
                  (Bone) {10.0, (angle_t) {0.0, 0.0, 20.0 / 180.0 * PI} },
                  (Bone) {4.0, (angle_t) {0.0, angles.euler4.pitch / 3, 0.0}},
                  (Bone) {3.0, (angle_t) {0.0, angles.euler4.pitch / 3, 0.0}},
                  (Bone) {3.0, (angle_t) {0.0, angles.euler4.pitch / 3, 0.0}} };
  
  std::vector<Vector3> thumb_skel = forward_kinematics(thumb);
  std::copy(++thumb_skel.begin(), thumb_skel.end(), m_data.thumb_coords);

  std::vector<Vector3> forefinger_skel = forward_kinematics(forefinger);
  std::copy(++forefinger_skel.begin(), forefinger_skel.end(), m_data.forefinger_coords);
  
  std::vector<Vector3> middle_skel = forward_kinematics(middle);
  std::copy(++middle_skel.begin(), middle_skel.end(), m_data.middle_coords);
  
  std::vector<Vector3> ring_skel = forward_kinematics(ring);
  std::copy(++ring_skel.begin(), ring_skel.end(), m_data.ring_coords);
  
  std::vector<Vector3> little_skel = forward_kinematics(little);
  std::copy(++little_skel.begin(), little_skel.end(), m_data.little_coords);

  m_data.palm_euler = angles.euler5;
  m_data.thumb_euler = angles.euler0;
  m_data.forefinger_euler = angles.euler1;
  m_data.middle_euler = angles.euler2;
  m_data.ring_euler = angles.euler3;
  m_data.little_euler = angles.euler4;

  pCharacteristic->setValue((uint8_t*)(&m_data), sizeof(m_data));
  Serial.println("Data sent");  
  pCharacteristic->notify();
}

class MyServerCallbacks: public BLEServerCallbacks
{
    void onConnect(BLEServer* pServer)
    {
      deviceConnected = true;
    };

    void onDisconnect(BLEServer* pServer)
    {
      deviceConnected = false;
    }
};
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

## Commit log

2022-06-02 Write READMEs
    [battery-case.f3d, motion-tracking-glove.3mf, mpu-mount .f3z]
2022-06-03 git: add mtg-drivers submodule
2022-06-03 feat: add esp32cam sketch
